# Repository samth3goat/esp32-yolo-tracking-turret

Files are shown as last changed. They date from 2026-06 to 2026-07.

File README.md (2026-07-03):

# ESP32 YOLO Object Tracking Turret

A real-time computer vision tracking system featuring a custom-designed and 3D-printed two-axis pan/tilt turret. The system uses a custom-trained YOLO11 model to detect and track a target object while an ESP32 microcontroller controls the turret through closed-loop PD control.

The project integrates mechanical design, computer vision, embedded systems, serial communication, and feedback control into a fully autonomous object tracking platform.

---

## Project Overview

The system captures live video using a webcam, processes each frame with OpenCV and a custom-trained YOLO11 model, computes the target's position relative to the center of the frame, and sends tracking commands to an ESP32. The ESP32 executes a PD controller to drive the pan and tilt servos, allowing the custom-designed turret to continuously maintain target lock through visual feedback.

---

## Skills Demonstrated

- Mechanical Design (CAD)
- 3D Printing
- Embedded Systems
- Computer Vision
- Control Systems (PD)
- OpenCV
- YOLO11
- ESP32
---

## Demo

Untitled - 05 juin 2026 à 16 11 36

---

## Features

- Custom-designed and 3D-printed pan/tilt turret
- Real-time object tracking using a custom-trained YOLO11 model
- Two-axis servo control with an ESP32 microcontroller
- OpenCV webcam integration
- Python ↔ ESP32 serial communication
- Closed-loop PD tracking controller
- Target coordinate extraction and smoothing
- Real-time visual debugging overlay
- External servo power system

---

## System Architecture

final system

Figure 1. High-level architecture of the closed-loop object tracking system. The webcam captures real-time video, the desktop computer performs YOLO11 inference and computes the tracking error, the ESP32 executes the PD controller and generates PWM signals, and the servos reposition the pan/tilt mechanism. The updated camera view provides continuous visual feedback, closing the control loop.

---
## Mechanical Design

The pan/tilt mechanism was designed from scratch in SolidWorks and manufactured using 3D printing. The assembly supports a Logitech C922 webcam and integrates two DS3218 servo motors to provide independent pan and tilt motion.

#### CAD Design

Untitled Project turret final Untitled Project

---

## Hardware

- Custom 3D-printed pan/tilt mechanism
- ESP32 DevKit V1
- 2 × DS3218 high-torque servo motors
- Logitech C922 USB webcam
- 5V 5A regulated external power supply

---

## Software Stack

- Python
- C++
- OpenCV
- Ultralytics YOLO11
- ESP32 Arduino Framework
- Arduino IDE

---

## Repository Structure
*In progress*
```text
esp32-yolo-tracking-turret/
│
├── README.md
├── requirements.txt
│
├── python/
│   ├── yolo_tracking.py
│   ├── serial_control.py
│   ├── camera_test.py
│   └── models/
│       └── custom_model.pt
│
├── esp32/
│   └── turret_control.ino
│
└── CAD/
    ├── servo assembly.SLDASM
    ├── servo head.SLDPRT
    ├── servo base.SLDPRT
    ├── servo mount.SLDPRT
    └── turret base.SLDPRT
```

---

## Installation

### Clone Repository

```bash
git clone https://github.com/samth3goat/esp32-yolo-tracking-turret.git
cd esp32-yolo-tracking-turret
```

---

### Install Python Dependencies

```bash
pip install -r requirements.txt
```

---

### Python Requirements

`requirements.txt`

```txt
opencv-python
ultralytics
pyserial
numpy
```

---

## Usage

### Run Object Detection

```bash
python python/yolo_tracking.py
```

---

### Upload ESP32 Firmware

1. Open Arduino IDE
2. Select board:

```text
ESP32 Dev Module
```

3. Select correct COM port
4. Upload:

```text
esp32/turret_control.ino
```

---

## Current Development Progress

### Completed
- [x] ESP32 setup and firmware upload
- [x] OpenCV webcam feed
- [x] YOLO object detection
- [x] Custom model loading
- [x] Initial ESP32 serial communication
- [x] Coordinate extraction from detections
- [x] Python to ESP32 movement commands
- [x] Pan tracking
- [x] Tilt tracking
- [x] PD control tuning
- [x] Final turret assembly

---

## Engineering Challenges

Some issues encountered during development:

- Training a custom YOLO model that could reliably identify the target while minimizing false detections.
- Balancing tracking accuracy and responsiveness to maintain smooth real-time performance.
- Establishing reliable serial communication between Python and the ESP32.
- Providing sufficient power for servo motors without causing instability or stalling.
- Tuning the tracking controller to reduce oscillation and improve target lock.

---

## Lessons Learned

This project is being used as a learning platform for:

- Computer vision using OpenCV and YOLO.
- Embedded systems programming with the ESP32.
- Serial communication between software and hardware.
- Servo control and power management.
- Control systems and real-time tracking.
- Debugging and integrating multi-component engineering systems.

---

## Notes

YOLO inference runs on the host PC, not the ESP32.

The ESP32 acts as the hardware controller for:
- servo movement
- future peripheral control

This architecture keeps computer vision processing separate from real-time hardware control.

---

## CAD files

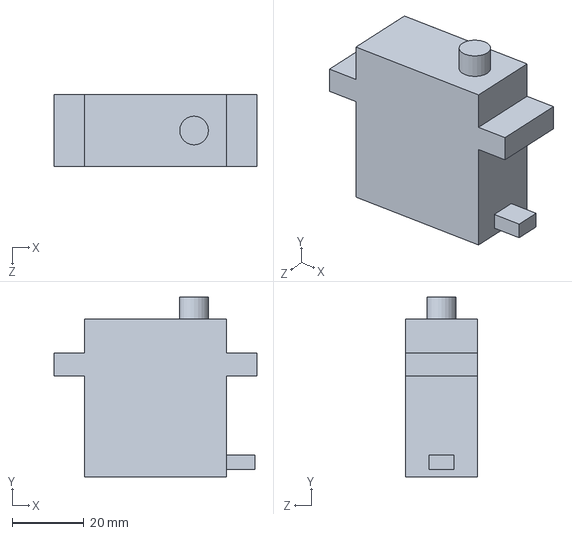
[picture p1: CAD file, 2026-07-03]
CAD/servo base.SLDPRT
56.5 x 50.0 x 20.0 mm

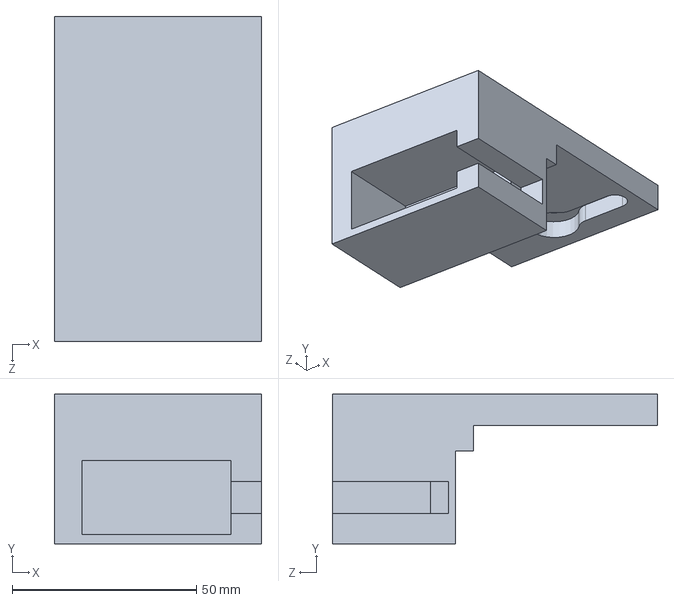
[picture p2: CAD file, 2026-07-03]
CAD/servo mount.SLDPRT
56.2 x 40.7 x 88.3 mm

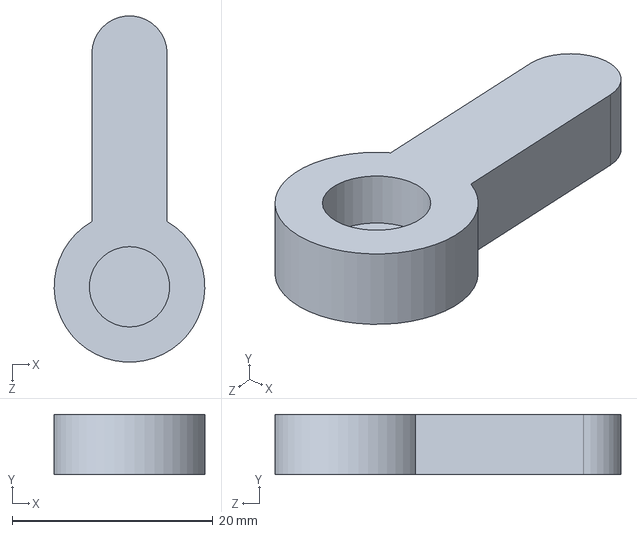
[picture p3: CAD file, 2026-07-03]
CAD/motor head.SLDPRT
15.0 x 6.00 x 34.4 mm

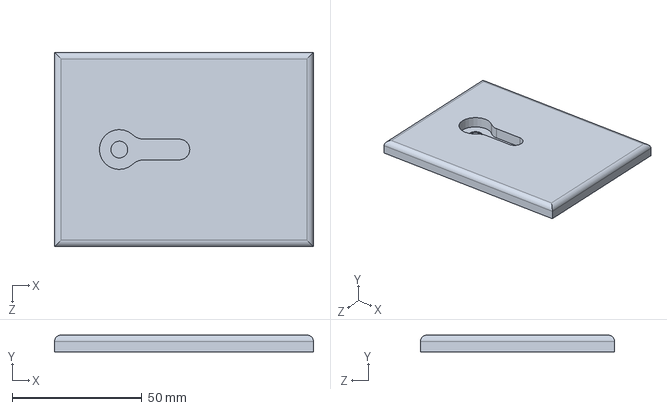
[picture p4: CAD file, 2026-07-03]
CAD/turret base.SLDPRT
100.0 x 6.50 x 75.0 mm

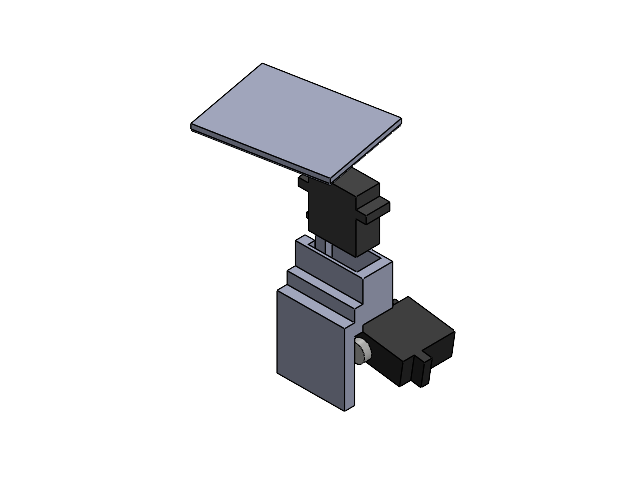
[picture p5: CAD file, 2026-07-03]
CAD/servo assembly.SLDASM
servo head x 2
motor head1 x 2
turret base
servo mount

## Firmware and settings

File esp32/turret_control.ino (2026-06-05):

#include <ESP32Servo.h>

Servo panServo;
Servo tiltServo;

float panAngle = 90;
float tiltAngle = 110;

// ===== TUNE THESE =====

float Kp = 0.005;
float Kd = 0.015;

// ======================

int prevXError = 0;
int prevYError = 0;

void setup() {

  Serial.begin(115200);

  panServo.attach(13);
  tiltServo.attach(12);

  panServo.write(panAngle);
  tiltServo.write(tiltAngle);
}

void loop() {

  if (Serial.available()) {

    String msg = Serial.readStringUntil('\n');

    int commaIndex = msg.indexOf(',');

    if (commaIndex > 0) {

      int xError =
          msg.substring(0, commaIndex).toInt();

      int yError =
          msg.substring(commaIndex + 1).toInt();

      int dx = xError - prevXError;
      int dy = yError - prevYError;

      // Deadzone

      if (abs(xError) > 5) {

        float panMove =
            (Kp * xError) +
            (Kd * dx);

        panMove = constrain(
            panMove,
            -7,
            7);

        panAngle -= panMove;
      }

      if (abs(yError) > 5) {

        float tiltMove =
            (Kp * yError) +
            (Kd * dy);

        tiltMove = constrain(
            tiltMove,
            -7,
            7);

        tiltAngle -= tiltMove;
      }

      prevXError = xError;
      prevYError = yError;

      panAngle = constrain(
          panAngle,
          20,
          160);

      tiltAngle = constrain(
          tiltAngle,
          20,
          160);

      panServo.write((int)panAngle);
      tiltServo.write((int)tiltAngle);
    }
  }
}

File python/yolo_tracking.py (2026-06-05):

from ultralytics import YOLO
import cv2
import serial
import time

model = YOLO("C:/Users/samue/Dropbox/My PC (DESKTOP-IB4HC17)/Downloads/turret project/python/models/custom_model1.pt")
cap = cv2.VideoCapture(0)

cap.set(cv2.CAP_PROP_FRAME_WIDTH, 1280)
cap.set(cv2.CAP_PROP_FRAME_HEIGHT, 720)

ser = serial.Serial("COM3", 115200)
time.sleep(2)

last_send = 0

# Smoothed target coordinates
smooth_cx = None
smooth_cy = None

# Smoothing factor
alpha = 0.8

while True:
    ret, frame = cap.read()

    if not ret:
        break

    results = model(frame, verbose=False)

    # Frame center (RED)
    frame_height, frame_width = frame.shape[:2]
    frame_cx = frame_width // 2
    frame_cy = frame_height // 2

    cv2.circle(frame, (frame_cx, frame_cy), 5, (0, 0, 255), -1)

    for r in results:
        for box in r.boxes:
            x1, y1, x2, y2 = box.xyxy[0]
            cx = int((x1 + x2)/2)
            cy = int((y1 + y2)/2)

            # Initialize smoothing
            if smooth_cx is None:
                smooth_cx = cx
                smooth_cy = cy

            smooth_cx = alpha * cx + (1 - alpha) * smooth_cx
            smooth_cy = alpha * cy + (1 - alpha) * smooth_cy

            smooth_cx_int = int(smooth_cx)
            smooth_cy_int = int(smooth_cy)

            # Green smoothed target dot
            cv2.circle(
                frame,
                (smooth_cx_int, smooth_cy_int),
                6,
                (0, 255, 0),
                -1
            )

            x_error = smooth_cx_int - frame_cx
            y_error = smooth_cy_int - frame_cy

            
            if time.time() - last_send > 0.02:

                message = f"{x_error},{y_error}\n"

                ser.write(message.encode())

                last_send = time.time()

            break

    frame = results[0].plot(img=frame)

    cv2.imshow("YOLO", frame)

    if cv2.waitKey(1) == ord('q'):
        break


cap.release()
ser.close()
cv2.destroyAllWindows()

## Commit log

2026-05-11 Revise README for ESP32 YOLO Object Tracking Turret
    Updated project title and expanded README content with detailed project overview, features, system architecture, hardware and software stack, installation instructions, usage, development progress, c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
2026-07-03 Revise README to include System Architecture and Mechanical Design
    Reintroduced the System Architecture section and added a Mechanical Design section with CAD images.
